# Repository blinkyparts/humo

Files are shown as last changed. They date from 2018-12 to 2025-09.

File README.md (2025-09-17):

# "Humo" Solder Fume Extractor

This simple solder fume extractor just needs a PC fan and an solder fume filter. If you add some gogglie eyes the fume extractor has a pretty nice smiling face. It is optimised for laser cutted parts.

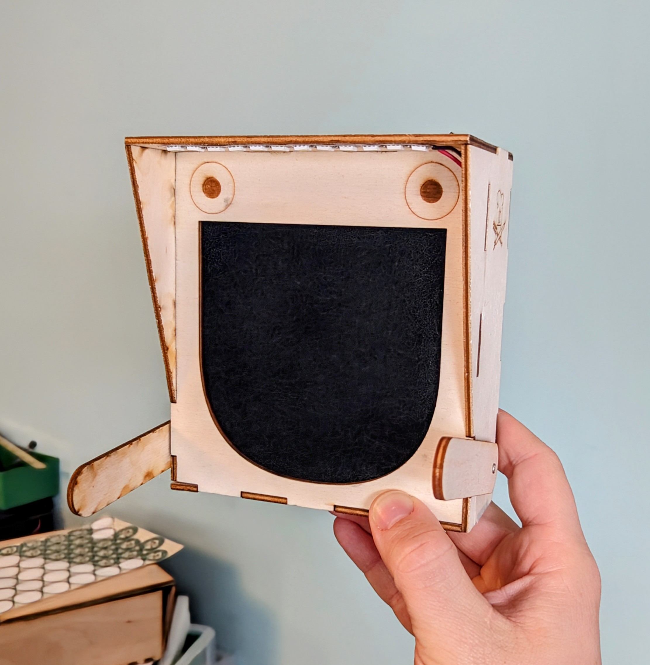
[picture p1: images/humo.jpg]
Humo is happy


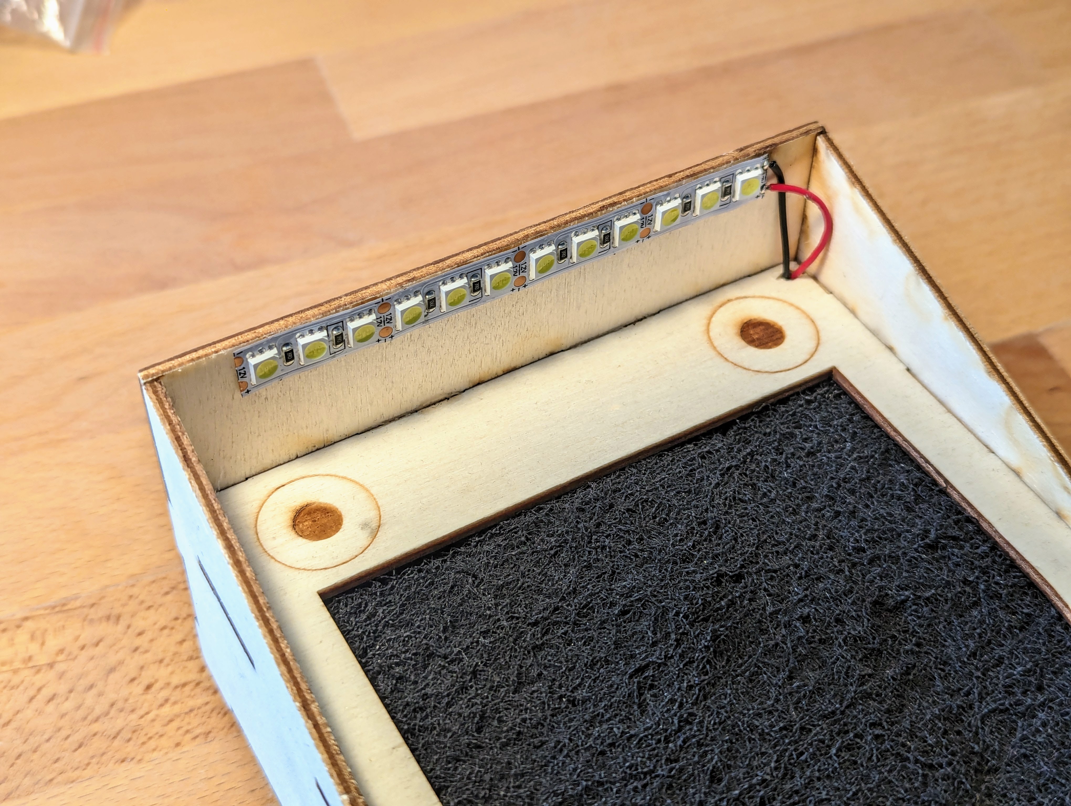
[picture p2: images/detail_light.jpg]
Humo has also light


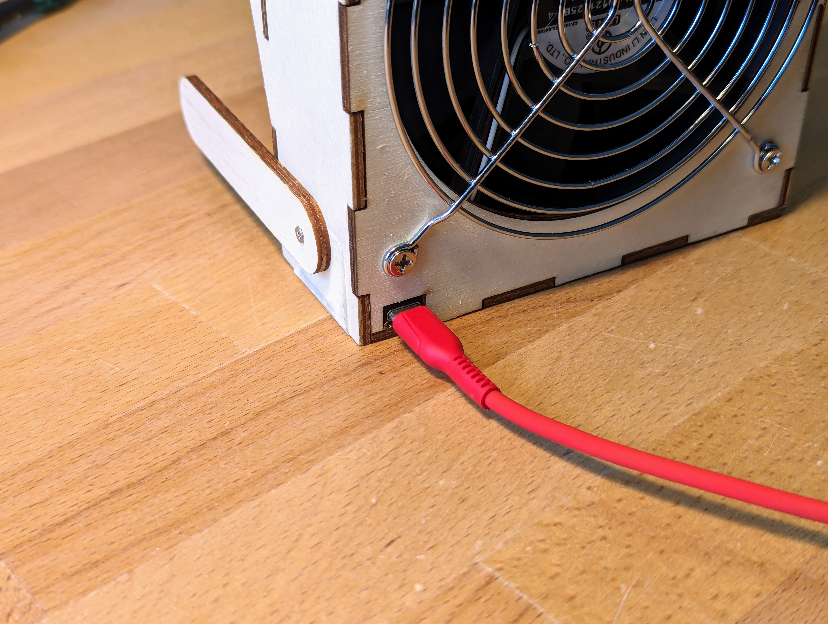
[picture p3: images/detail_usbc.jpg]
Humo loves USBC PD


## Lasered Parts
The box for the lasered parts has been created with an kerf of 0,2mm. The different colours stand for:

- Red: Cut part
- Black: Scan part
- Green: Grave part

Please adjust your laser cutter.

## Neded Parts

### Version 1.1
This version uses a external 12V power supply.

| Description | Quantity | Description / Example |
|:---:|:---:|:---:|
| Laser cutted 3mm wooden parts | 1 | - |
| PC fan 120mm | 1 | Logilink FAN103 120x120x25mm (Pollin: 320377) |
| Power supply 12V | 1 | Stecker-Schaltnetzteil MV-12 (Pollin: 352213) |
| Power supply socket | 1 | Einbau-Hohlbuchse (Pollin: 450596) |
| Fan grill | 1 | Lüftergitter 120x120 mm (Pollin: 320660) |
| PC fan screw | 4 | Aliexpress "pc fan screw" |
| Solderfume Filter | 1 | Ersatzfilter Lötrauchabsaugung (Reichelt: FILTER ZD-153 EF) |
| Woodscrew 		| 2 | M2.2x8mm |

### Version 2.0
This version uses a DC-DC step up converter from 5V to 12V.

| Description | Quantity | Description / Example |
|:---:|:---:|:---:|
| Laser cutted parts | 1 | 3mm wood |
| PC fan 120mm | 1 | Logilink FAN103 120x120x25mm (Pollin: 320377) |
| PC fan screws | 4 | Aliexpress "pc fan screw" |
| Fan grill | 1 | Lüftergitter 120x120 mm (Pollin: 320660) |
| Solderfume Filter  | 1 | Ersatzfilter Lötrauchabsaugung (Reichelt: FILTER ZD-153 EF) |
| 5V to 12V step up  | 1 | MT3608 DC-DC |
| Woodscrew | 2 | M2.2x8mm |

### Version 2.2
This version has light, useses USBC to 12V adapter and a much better fan. It has now also a switch to turn it on and off.

| Description | Quantity | Description / Example |
|:---:|:---:|:---:|
| Laser cutted parts | 1 | 3mm wood |
| PC fan 120mm | 1 | SUNON MEC0251V3-000U-A99 (Reichelt: SUN MEC0251V3-0 |
| PC fan screws | 4 | Aliexpress "pc fan screw" |
| Fan grill | 1 | Fan grill 120x120 mm (Pollin: 320660) |
| Solderfume Filter  | 1 | Replacement filter (Reichelt: FILTER ZD-153 EF) |
| 5V to 12V step up  | 1 | PDC004-PD USBC trigger board |
| Woodscrew | 2 | M2.2x8mm |
| LED stripe | 10cm | 12V warm white LED stripe |
| Wire | 15cm | Some flexible wire any colour/size |
| Switch | 1 | On-Off-Toggle-Switch |

### Version 2.3
This version removes the need for the fan grill, as it's integrated in the design.
(otherwise the same as the version above)

| Description | Quantity | Description / Example |
|:---:|:---:|:---:|
| Laser cutted parts | 1 | 3mm wood |
| PC fan 120mm | 1 | SUNON MEC0251V3-000U-A99 (Reichelt: SUN MEC0251V3-0 |
| PC fan screws | 4 | Aliexpress "pc fan screw" |
| Solderfume Filter  | 1 | Replacement filter (Reichelt: FILTER ZD-153 EF) |
| 5V to 12V step up  | 1 | PDC004-PD USBC trigger board |
| Woodscrew | 2 | M2.2x8mm |
| LED stripe | 10cm | 12V warm white LED stripe |
| Wire | 15cm | Some flexible wire any colour/size |
| Switch | 1 | On-Off-Toggle-Switch |

## Buy Parts online
You can also buy a kit with all needes parts (always the newest version) at blinkyparts:

[Humo - Soldering Kit](https://shop.blinkyparts.com/de/Humo-Dein-ganz-persoenlicher-Loetrauchabsauger/blipa231042)

## What does "Humo" stand for?
The hardest part for every project: The Name. Humo is spain for "fume". Props to zaesa for this hint :).

## Copyright and Authorship
Humo is licenced under [CC-BY-SA 4.0](https://creativecommons.org/licenses/by-sa/4.0/) - [Timo Schindler](https://www.timoschindler.de).

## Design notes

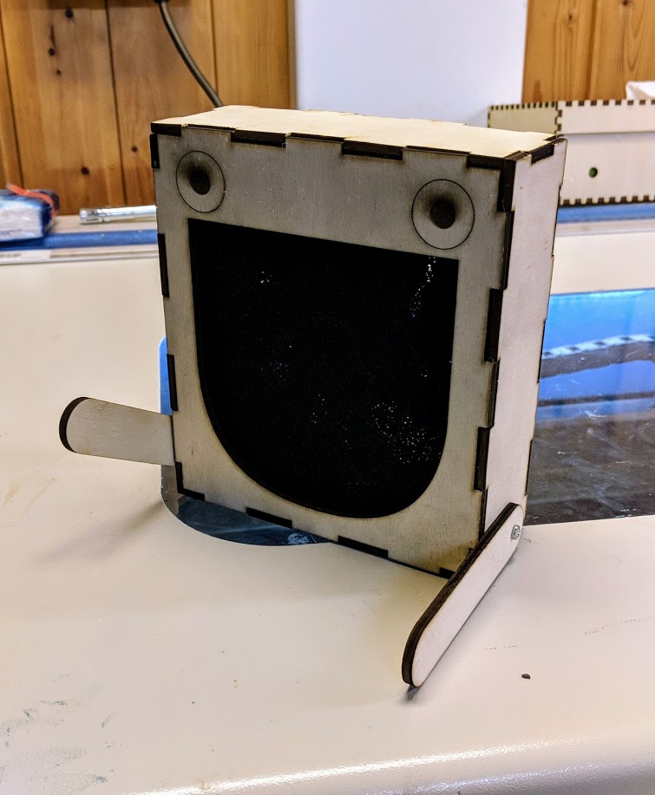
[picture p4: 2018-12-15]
images/humo_v1.0.jpg

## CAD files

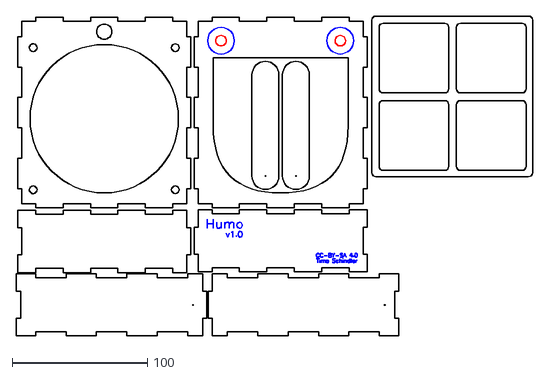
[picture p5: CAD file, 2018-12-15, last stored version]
humo_120x120mm_3mm_mk2.dxf
382.2 x 236.9

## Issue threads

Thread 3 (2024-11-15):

Humo 2.2 Setup problem

mr-gosh, 2024-11-15:
What todo if there are only 5v at the end of the led stripe?

marove2000, 2024-11-20:
Hi @mr-gosh unfurtunately the old step-up modules are a little buggy. Try to give the blue part a light stroke. It is sometimes stuck. And then use a screw to adjust the Voltage to 12V.

mr-gosh, 2025-02-16:
> Hi @mr-gosh unfurtunately the old step-up modules are a little buggy. Try to give the blue part a light stroke. It is sometimes stuck. And then use a screw to adjust the Voltage to 12V.

I glued it into place - where to "screw" for adjustment?
Can't see any poti-like part?!?
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

marove2000, 2025-02-17:
Hi, thanks for the photo. That clarifies a lot! You already have the new module, there is no potentiometer. The fact that you are only getting 5V is most likely due to the fact that your power supply is not delivering more than 5V. With Power Delivery, the module and power supply unit must first negotiate the 12V. Have you already used a different power supply unit?

mr-gosh, 2025-02-19:
>  Have you already used a different power supply unit?

Yes - I tried multiple USB-C power delivery compatible devices.
Dell Notebook Chargers, Steam Deck power supply, and multiple phone chargers with 12v support printed on.
What else can i do?

I thought about buying a pack of adapters or replacement modules?

marove2000, 2025-02-21:
I assume you got it from https://shop.blinkyparts.com ? Or at some chaos-event? Just write us an email and we'll send you a replacement :).

Regards

mr-gosh, 2025-02-23:
I bought it on the Makerfaire - so i will send you an mail to shop@blinkyparts.com
THX

mr-gosh, 2025-04-14:
THX for exchanging the defect part.
Seems that it was really only the defect usb-c port that always exported 5v and not the necessary 12v

Closed 2025-03-03.

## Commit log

2018-12-15 added final MK2
    [humo_120x120mm_3mm_mk2.dxf]
2019-01-07 updated box design. Added binary kitchen logo
    [humo_120x120mm_3mm_mk2.dxf]
2019-01-07 added description for laser
2021-01-04 added BOM for version 2.0
2024-01-01 added hex pattern grill to fan cut out
